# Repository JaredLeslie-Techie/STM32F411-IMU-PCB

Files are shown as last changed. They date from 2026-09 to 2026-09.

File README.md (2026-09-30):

# STM32F411 IMU PCB Design

A four-layer PCB design in Altium Designer built around the **STM32F411CEU6** microcontroller and an **MPU-6050** inertial measurement unit (IMU). The repository contains the editable Altium design, STM32CubeMX pin configuration, bill of materials, Gerber X2 exports, and design visualizations.

> **Project status:** Designed only. This board has **not** been manufactured, assembled, powered, or tested. The included Gerbers are design exports for review, not a validated fabrication release. The saved design rule check reports 153 unwaived violations; see [Design status](DESIGN_STATUS.md) before considering fabrication.

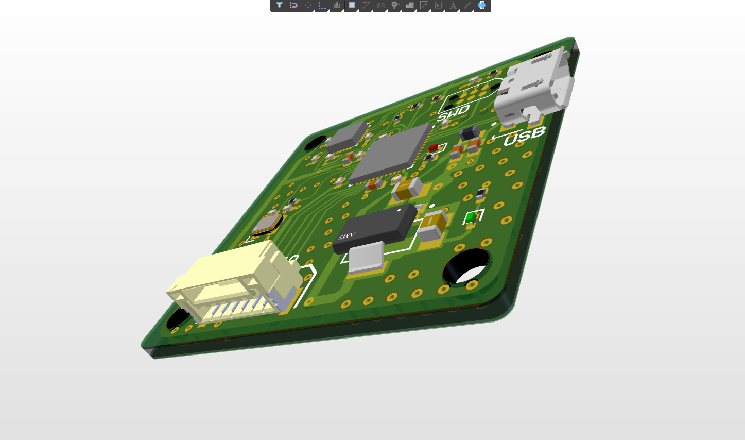
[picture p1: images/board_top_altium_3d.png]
Altium Designer 3D view of the STM32F411 IMU PCB showing component placement


*Altium Designer 3D view showing the intended component placement. This is a CAD rendering, not a photograph of a manufactured or assembled board. See the [unpopulated top-side view](images/board_top.png) for the Gerber-derived artwork.*

## Design overview

| Item | Design detail |
|---|---|
| Microcontroller | STM32F411CEU6, as listed in the BOM |
| Motion sensor | MPU-6050 accelerometer and gyroscope; I2C1 uses PB6 (SCL) and PB7 (SDA) in the supplied `.ioc` file |
| USB and power | Micro-USB connector and AMS1117-3.3 regulator; PA11/PA12 are configured for USB FS in STM32CubeMX |
| Debug and I/O | SWD signals on PA13/PA14; a six-position connector and LED footprints are included |
| Clock | 24 MHz crystal listed in the BOM |
| PCB | Four copper signal layers; outline approximately 37 × 37 mm |

The `.ioc` file also assigns PB8 as `IMU_INT` and PB13 as a GPIO output named `LED`. It is a peripheral configuration file; **no firmware is included** in this repository.

## PCB and schematic images

| Bottom side, viewed from underneath | Top copper routing |
|---|---|
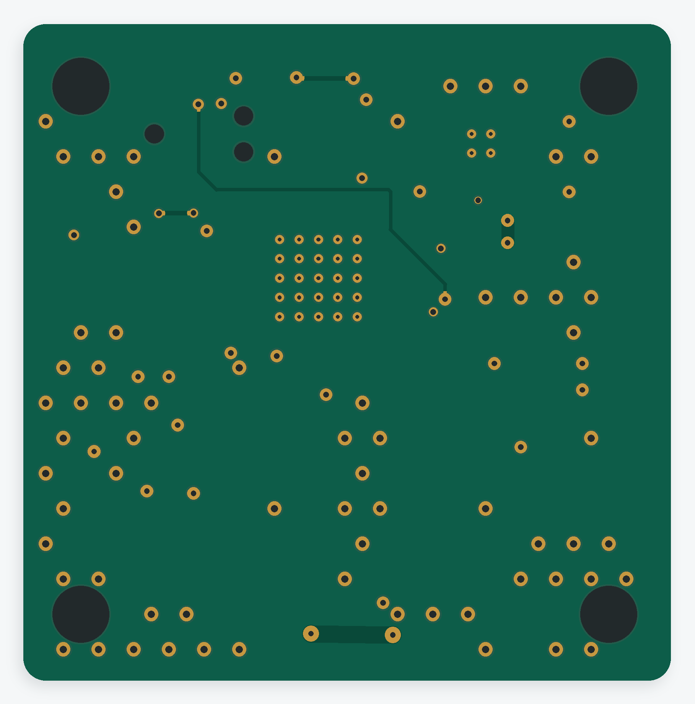
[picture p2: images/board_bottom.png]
Bottom-side Gerber preview
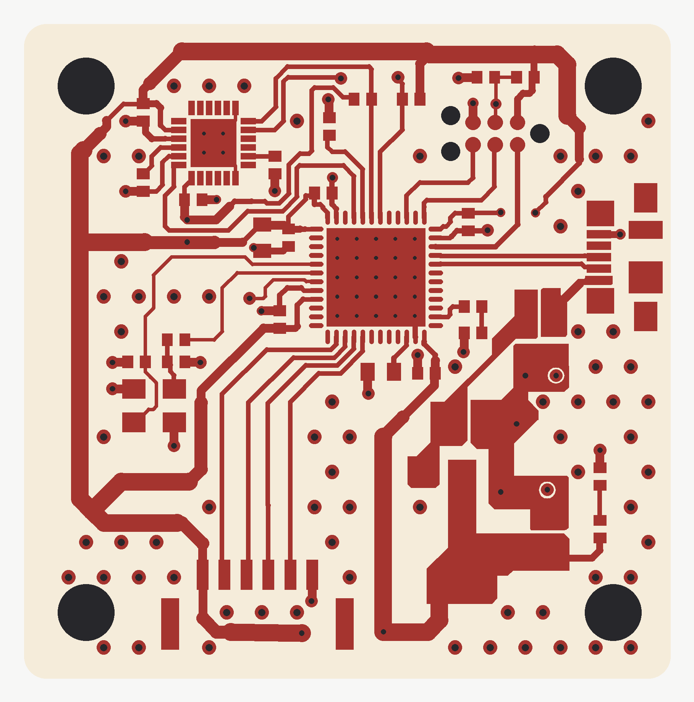
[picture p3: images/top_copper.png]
Top copper routing plot
|  |  |

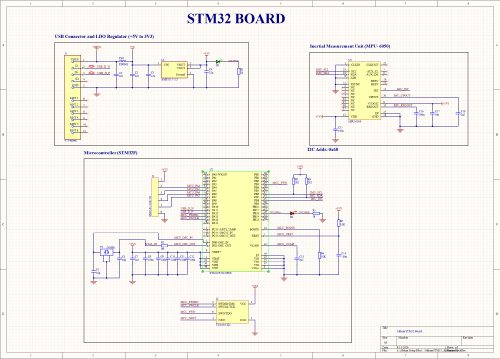
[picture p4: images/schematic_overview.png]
Small overview preview extracted from the supplied Altium schematic


*The schematic thumbnail is a low-resolution preview saved with the Altium project. Open the `.SchDoc` file in Altium for readable schematic details. The top and bottom flat board previews are derived from the supplied Gerber exports.*

## Files

| Path | Contents |
|---|---|
| `AltiumSTM32.PrjPcb` | Altium Designer project |
| `AltiumSTM32_Schematic.SchDoc` | Editable schematic |
| `AltiumSTM32_PCB.PcbDoc` | Editable PCB layout |
| `AltiumSTM32.ioc` | STM32CubeMX pin and peripheral configuration |
| `images/` | Altium 3D screenshot, flat top and bottom Gerber previews, top copper plot, and schematic thumbnail |
| `bom/Bill_Of_Materials.csv` | Supplied component list |
| `gerbers/` | Supplied Gerber X2 layer and drill exports |
| `reports/Design_Rule_Check_2026-09-13.drc` | Saved DRC report with its local file path removed |
| `DESIGN_STATUS.md` | Design review findings and limits |

## Open and review the design

1. Open `AltiumSTM32.PrjPcb` in Altium Designer to inspect the schematic and PCB.
2. Review the BOM and the Gerber files against the Altium source. The original project references two external Altium libraries named `Schematic-Lib-PhilsLab.SchLib` and `Footprint-Lib-PhilsLab.PcbLib` in a neighboring folder; those library files were not supplied and are not included here.
3. If you modify the design or plan to manufacture it, resolve the remaining design rule violations, verify the schematic and footprints, and regenerate and inspect all manufacturing outputs.

See [Design status](DESIGN_STATUS.md) for the saved DRC findings. Physical function and fabrication suitability have not been verified.

## Credits

The original Altium project references schematic and footprint libraries named for **Phil's Lab**. Thanks to [Phil's Lab (Philip Salmony)](https://github.com/pms67) for sharing PCB design resources. The referenced external library files were not part of the supplied project archive and are not included in this repository.

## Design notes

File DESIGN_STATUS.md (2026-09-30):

# Design status and review notes

This repository presents an **unfabricated design**. There are no assembly photographs, hardware measurements, or physical test results in the supplied archive. The Gerber files are supplied exports and should be regenerated and checked against the Altium project before any fabrication order.

## Saved design rule check

The later DRC report in the supplied project's output folder is dated **13 September 2026, 20:49:57**. It reports **153 violations detected and 0 waived**:

| Rule | Violations | Review needed |
|---|---:|---|
| Hole size | 4 | Four 3.2 mm mounting holes exceed the saved rule's 2.54 mm maximum. Confirm the intended mounting-hole specification and adjust the rule or design. |
| Minimum solder mask sliver | 139 | Check the mask openings and the selected fabricator's capabilities, especially around fine-pitch parts and vias. |
| Silkscreen to solder mask clearance | 10 | Inspect and move or adjust affected legend features. |
| **Total** | **153** | No violations were marked as waived in this report. |

The same report lists **0** clearance, short-circuit, and un-routed-net violations. That does not establish electrical or manufacturing correctness. An older DRC report also existed in the archive; this package includes the later report to keep the review baseline clear. The Gerber export status report was generated later on the same date, at **21:15:01**, so rerun DRC and regenerate all outputs from the final source before using them for production.

## Project dependencies

`AltiumSTM32.PrjPcb` refers to `Schematic-Lib-PhilsLab.SchLib` and `Footprint-Lib-PhilsLab.PcbLib` by relative paths outside the supplied folder. Those third-party library files were not included in the archive and are not redistributed here. Altium may prompt for the libraries when updating components or footprints.

The board images are generated from the provided Gerber data, and the small schematic overview comes from Altium's saved preview. They are **design visualizations**, not photographs of assembled hardware.

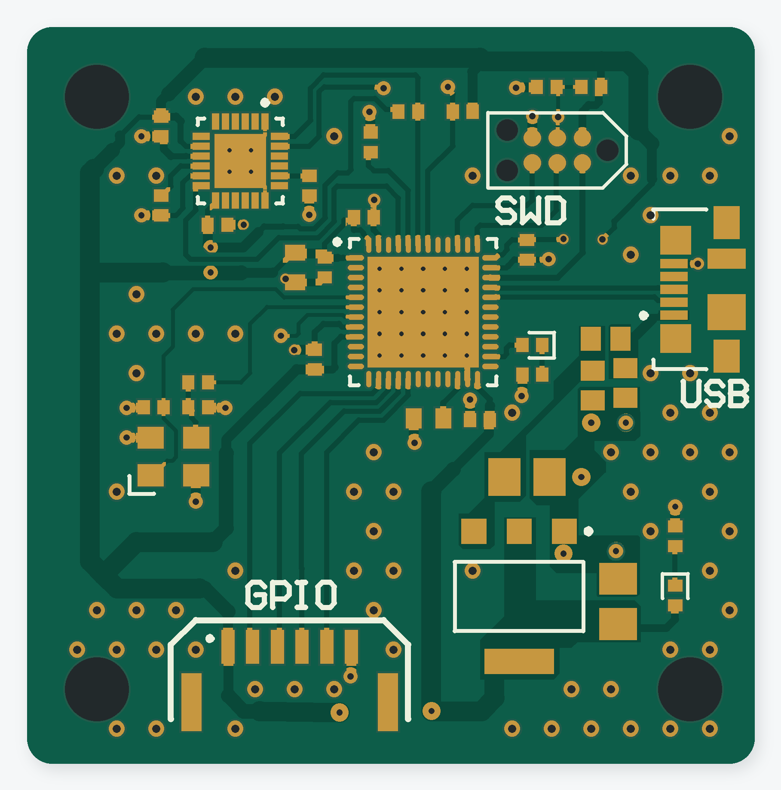
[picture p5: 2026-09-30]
images/board_top.png

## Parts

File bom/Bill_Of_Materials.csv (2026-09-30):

Comment | Description | Designator | Footprint | LibRef | Quantity
2u2 | Capacitor SMD 0603 16V | C1, C2, C7, C13 | CAP_0603 | CAP_0603_16V | 4
22u | Capacitor SMD 0805 16V | C3, C4 | CAP_0805 | CAP_0805_16V | 2
10p | Capacitor SMD 0402 16V | C5, C6 | CAP_0402 | CAP_0402_16V | 2
100n | Capacitor SMD 0402 16V | C8, C9, C10, C11, C12, C14, C15, C16 | CAP_0402 | CAP_0402_16V | 8
10n | Capacitor SMD 0402 16V | C17 | CAP_0402 | CAP_0402_16V | 1
2n2 | Capacitor SMD 0402 16V | C18 | CAP_0402 | CAP_0402_16V | 1
GREEN | LED 0402 GREEN SMD | D1 | LED_0402_GREEN | LED_0402_GREEN | 1
RED | LED 0402 RED SMD | D2 | LED_0402_RED | LED_0402_RED | 1
FB0603 | Ferrite Bead SMD 0603 | FB1 | FB_0603 | FB_0603 | 1
473460001 | CONN RCPT USB2.0 MICRO B SMD R/A | J1 | FP-473460001-MFG | CMP-2000-05246-2 | 1
SM06B-GHS-TB | Header Connector 6 Position 1.25MM Pitch SMD Horizontal JST GH | J3 | SM06B-GHS-TB | SM06B-GHS-TB | 1
1k | Resistor SMD 0402 | R1, R5 | RES_0402 | RES_0402 | 2
0R | Resistor SMD 0402 | R2 | RES_0402 | RES_0402 | 1
2k2 | Resistor SMD 0402 | R3, R4 | RES_0402 | RES_0402 | 2
10K | Resistor SMD 0402 | R6, R7 | RES_0402 | RES_0402 | 2
AMS1117-3.3 | LDO Voltage Regulators 1A, 3.3V | U1 | FP-AMS1117-IPC_C | CMP-209535-000001-1 | 1
STM32F411CEU6 | ARM Cortex-M4 32-bit MCU+FPU, 512 KB Flash, 128 KB RAM, 36 I/Os, 48-Pin UFQFPN, -40 to 85 degC, Tray | U2 | STM-UFQFPN48_L | CMP-0243-00165-1 | 1
MPU-6050 | 3-Axis Gyroscope, Accelerometer and a Digital Motion Processor(TM) (DMP), 2.375 to 3.46 V, -40 to 85 degC, 24-Pin QFN, RoHS, Tape and Reel | U3 | IS-QFN-24_V | CMP-1753-00002-2 | 1
24MHz | Crystal SMD 24MHz 10PPM 7pF 3225 | Y1 | XTAL_3225 | TSX-3225_24.0000MF15X-AC | 1

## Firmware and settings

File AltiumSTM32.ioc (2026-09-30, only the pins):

Mcu.UserName=STM32F411CEUx
PA11.Signal=USB_OTG_FS_DM
PA12.Signal=USB_OTG_FS_DP
PA13.Signal=SYS_JTMS-SWDIO
PA14.Signal=SYS_JTCK-SWCLK
PB13.GPIO_Label=LED
PB13.Signal=GPIO_Output
PB3.Signal=SYS_JTDO-SWO
PB6.Signal=I2C1_SCL
PB7.Signal=I2C1_SDA
PB8.GPIO_Label=IMU_INT
PB8.Signal=GPXTI8

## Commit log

2026-09-30 Add STM32F411 IMU PCB design and documentation
    [AltiumSTM32.PrjPcb, AltiumSTM32_PCB.PcbDoc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]
2026-09-30 Add 3D PCB Image
